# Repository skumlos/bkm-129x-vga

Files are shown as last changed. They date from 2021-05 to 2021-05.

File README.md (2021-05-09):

The BKM-129X compatible with VGA instead of BNC.

Including a sync combiner circuit to run with both CSYNC and HVSYNC. This circuit was made up
by Ste from HD Retrovision as far as I know.

Requires Arduino Nano v3.0 loaded with the software from https://github.com/skumlos/bkm-129x-mcu

Revision log:

B: Fixed THS7374 bypass and VGA pin 9 connectivity. Update to Kicad 5.

A: Initial revision

(2020) Martin Hejnfelt (martin@hejnfelt.com)

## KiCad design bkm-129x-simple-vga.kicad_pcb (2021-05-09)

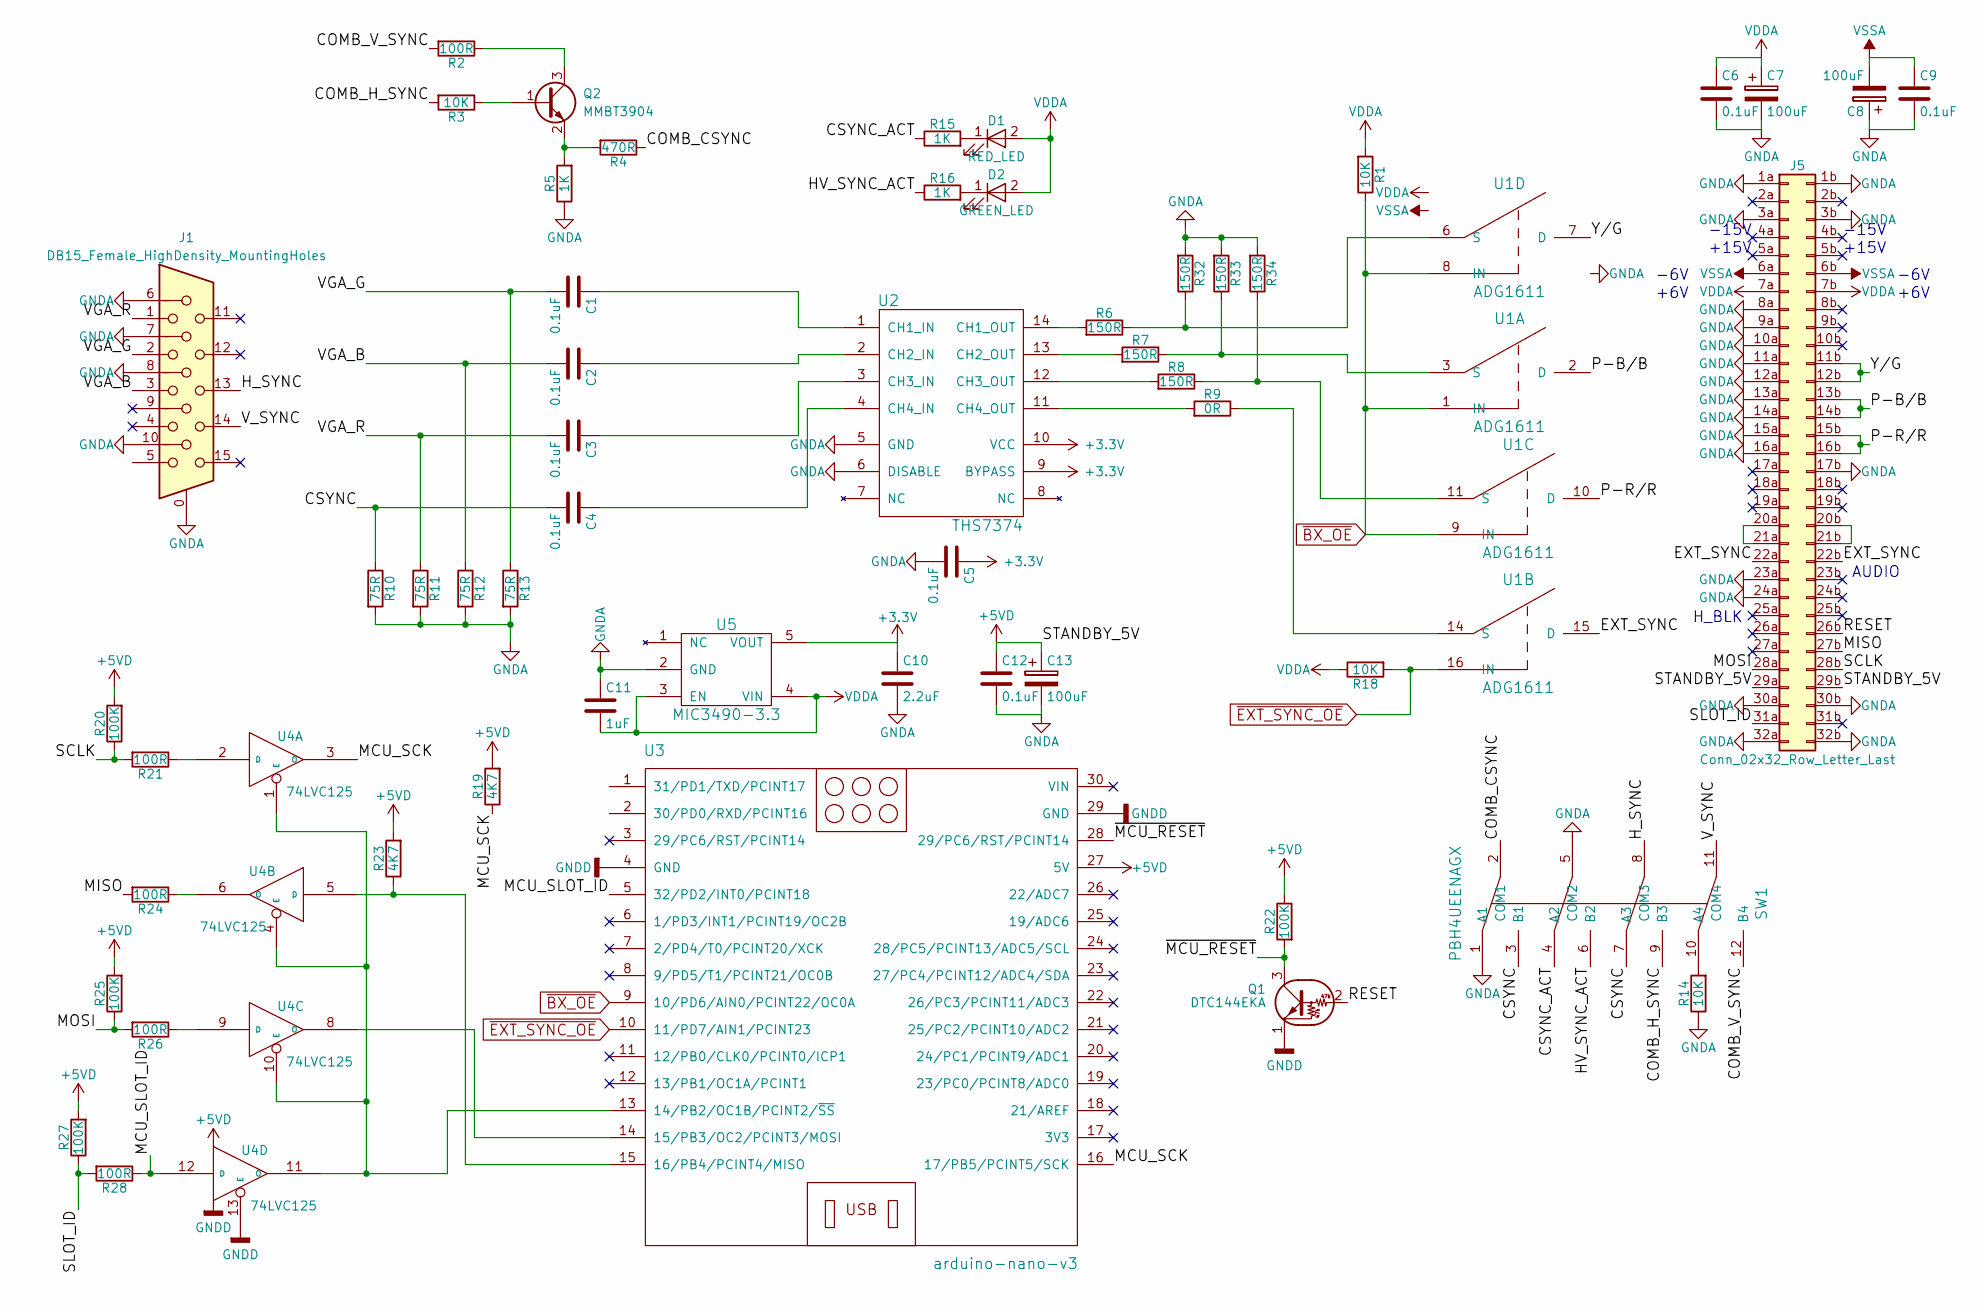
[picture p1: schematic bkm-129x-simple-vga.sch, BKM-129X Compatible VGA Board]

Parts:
C1, C2, C3, C4, C5, C6, C9, C12: 0.1uF; C_0805_HandSoldering
C7, C8, C13: 100uF; CP_Elec_6.3x5.3
C10: 2.2uF; C_0805_HandSoldering
C11: 1uF; C_0805_HandSoldering
D1: RED_LED; D_0805
D2: GREEN_LED; D_0805
J1: DB15_Female_HighDensity_MountingHoles; HD15-VGA
J5: Conn_02x32_Row_Letter_Last; DIN-41612-64P
Q1: DTC144EKA; SC-59_Handsoldering
Q2: MMBT3904; SOT-23_Handsoldering
R1, R3, R14, R18: 10K; R_0805_HandSoldering
R2, R21, R24, R26, R28: 100R; R_0805_HandSoldering
R4: 470R; R_0805_HandSoldering
R5, R15, R16: 1K; R_0805_HandSoldering
R6, R7, R8, R32, R33, R34: 150R; R_0805_HandSoldering
R9: 0R; R_0805_HandSoldering
R10, R11, R12, R13: 75R; R_0805_HandSoldering
R19, R23: 4K7; R_0805_HandSoldering
R20, R22, R25, R27: 100K; R_0805_HandSoldering
SW1: PBH4UEENAGX; PBH4UEE
U1: ADG1611; TSSOP-16_4.4x5mm_Pitch0.65mm
U2: THS7374; TSSOP-14_4.4x5mm_Pitch0.65mm
U3: arduino-nano-v3
U4: 74LVC125; TSSOP-14_4.4x5mm_Pitch0.65mm
U5: MIC3490-3.3; SOT-23-5_HandSoldering

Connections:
+3V3: C5.1, C10.1, U2.9 (BYPASS), U2.10 (VCC), U5.5 (VOUT)
+5VD: C12.1, C13.1, J5.29a, J5.29b, R19.2, R20.2, R22.1, R23.2, R25.2, R27.2, U3.27 (5V), U4.14 (VCC)
/COMB_CSYNC: R4.1, SW1.2 (COM1)
/COMB_H_SYNC: R3.2, SW1.9 (B3)
/COMB_V_SYNC: R2.2, SW1.12 (B4)
/CSYNC: C4.2, R10.1, SW1.3 (B1), SW1.7 (A3)
/CSYNC_ACT: R15.1, SW1.4 (A2)
/EXT_SYNC: J5.22a, J5.22b, U1.15 (D)
/HV_SYNC_ACT: R16.1, SW1.6 (B2)
/H_SYNC: J1.13, SW1.8 (COM3)
/MCU_SCK: R19.1, U3.16 (17/PB5/PCINT5/SCK), U4.3 (O)
/MCU_SLOT_ID: R28.1, U3.5 (32/PD2/INT0/PCINT18), U4.12 (D)
/MISO: J5.27b, R24.2
/MOSI: J5.28a, R25.1, R26.2
/P-B/B: J5.13b, J5.14b, U1.2 (D)
/P-R/R: J5.15b, J5.16b, U1.10 (D)
/RESET: J5.26b, Q1.2 (B)
/SCLK: J5.28b, R20.1, R21.2
/SLOT_ID: J5.31a, R27.1, R28.2
/VGA_B: C2.2, J1.3, R12.1
/VGA_G: C1.2, J1.2, R13.1
/VGA_R: C3.2, J1.1, R11.1
/V_SYNC: J1.14, SW1.11 (COM4)
/Y/G: J5.11b, J5.12b, U1.7 (D)
/~MCU_RESET: Q1.3 (C), R22.2, U3.28 (29/PC6/RST/PCINT14)
unnamed: C1.1, U2.1 (CH1_IN)
unnamed: C2.1, U2.2 (CH2_IN)
unnamed: C3.1, U2.3 (CH3_IN)
unnamed: C4.1, U2.4 (CH4_IN)
unnamed: D1.1 (K), R15.2
unnamed: D2.1 (K), R16.2
unnamed: J5.20a, J5.21a
unnamed: J5.20b, J5.21b
unnamed: Q2.1 (B), R3.1
unnamed: Q2.2 (E), R4.2, R5.2
unnamed: Q2.3 (C), R2.1
unnamed: R6.2, U2.14 (CH1_OUT)
unnamed: R7.2, U2.13 (CH2_OUT)
unnamed: R8.2, U2.12 (CH3_OUT)
unnamed: R9.1, U1.14 (S)
unnamed: R9.2, U2.11 (CH4_OUT)
unnamed: R14.2, SW1.10 (A4)
unnamed: R21.1, U4.2 (D)
unnamed: R23.1, U3.15 (16/PB4/PCINT4/MISO), U4.5 (D)
unnamed: R24.1, U4.6 (O)
unnamed: R26.1, U4.9 (D)
unnamed: R6.1, R32.1, U1.6 (S)
unnamed: R7.1, R33.1, U1.3 (S)
unnamed: R8.1, R34.1, U1.11 (S)
unnamed: U3.13 (14/PB2/OC1B/PCINT2/~SS), U4.1 (E), U4.4 (E), U4.10 (E), U4.11 (O)
unnamed: U3.14 (15/PB3/OC2/PCINT3/MOSI), U4.8 (O)
VDD: C6.1, C7.1, C11.2, D1.2 (A), D2.2 (A), J5.7a, J5.7b, R1.2, R18.1, U1.13 (VDD), U5.3 (EN), U5.4 (VIN)
VSS: C8.2, C9.1, J5.6a, J5.6b, U1.4 (VSS)
~BX_OE: R1.1, U1.1 (IN), U1.8 (IN), U1.9 (IN), U3.9 (10/PD6/AIN0/PCINT22/OC0A)
~EXT_SYNC_OE: R18.2, U1.16 (IN), U3.10 (11/PD7/AIN1/PCINT23)

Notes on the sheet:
-15V
+15V
-6V
+6V
AUDIO
H_BLK

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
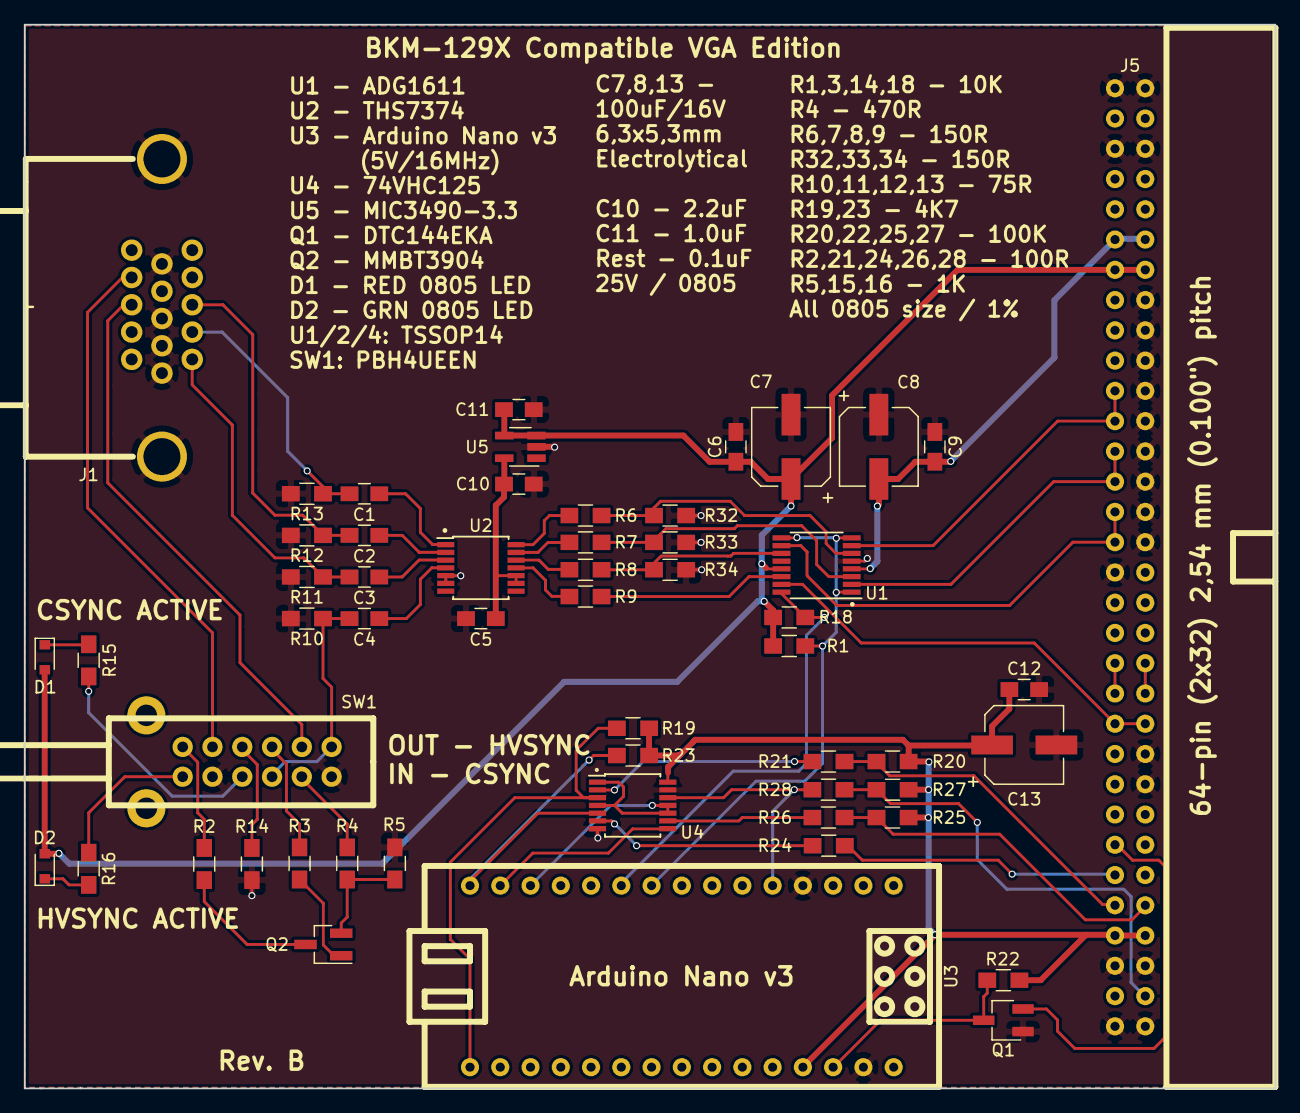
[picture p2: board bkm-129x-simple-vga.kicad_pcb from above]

Board: 2 copper layers, 105.0 x 89.3 mm, 55 parts (0 on the bottom side), 56 nets.

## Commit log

2021-05-09 Rev. B: Fix THS7374, VGA pin 9, Kicad 5
    [bkm-129x-simple-vga.kicad_pcb, bkm-129x-simple-vga.sch]
2021-05-09 Added some missing Kicad files
